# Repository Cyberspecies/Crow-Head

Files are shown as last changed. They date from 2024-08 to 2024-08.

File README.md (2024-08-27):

# Crow Head
The crow head series began as a torture test and a way to consolidate the knowledge gained. Additionally it is designed to test ideas and features that are included within other projects. The head's are allowed to be worked upon however they are not allowed to have more versions, rather once a design is finished, the majority of the design must remain and any other ideas must be tested upon the finished version or put forth to the next design.

### Note:
STL Files won't be provided due to github's file upload size restrictions. Although some files are small enough to fit, it won't be a good practice if only some files are available. There are many other programs and ways to convert step to stl so it should not be much of an issue. If it is a large issue to convert the file please make an issue with this repo or add to existing ones stating it and I will concider it, however it will be difficult to keep it up on 1 platform such at github.

## D1
The first design for this is a very simple head designed to test whether or not I could build the head within a week from start to finish. Although This version did not have the best shape, it was good enough to serve its purpose.
CrowHeadV1

## D2
The second design fixes the problems of the first design to be very comfortable to wear. This version looked more like a motor bike helmet and could be worn for hours, however I did have some issues with vision due to the mesh but ventillation was significantly improved due to it.
CrowHeadV2

## D3
This design builds off the previous variant to be a good combination between great vision and decent ventillation. Although this version looks ok, it doesnt really fix the issues rather it just reduces them a bit. This version is the first design to combine reflective plates in the eyes to allow an LED system to be integrated directly.
CrowHeadV3

## D4 (In Progress)
This design will be more of a cosplay style rather then purely hard plastic shells. The main point of this version is to be simiar to D3 however fixing many of the ventillation and vision warping issues whilst also having the capability of being water proof.

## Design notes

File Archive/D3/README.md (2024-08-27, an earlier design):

# Crow Head V3
V3 was the first to contain electrical components that were integrated directly into the build rather then being added in post. This was also the first version to have a vacuum formed visor rather then the mesh.

## Known Issues
* Visor fogs up as there is no active ventillation that is properly implemented nor any way to redirect the moist breath.
* The head retention mechanism is still lacking as the strap must be manually tensioned to the head.
* No way to attach the visor to the rest of the head without welding it or with other adhesives.

## Structure
Similar to previous models, you are required to weld the sections together, the eyes do require a bit of assembly and visor vacuum formed.
CrowHeadV3Diagram

* [Crow Head V3.f3z](Crow%20Head%20V3.f3z): Contains the entire project, however the visor buck was lost so I uploaded the latest version that was produced.
* [Crow Head V3.step](Crow%20Head%20V3.step): A step file export of the project, incase you don't have Fusion 360.
* [Crow Head V3 Cuts.step](Crow%20Head%20V3%20Cuts.step): This file contains all of the cuts required to fabricate the build.
* [Crow Head V3 Visor Buck.f3d](Crow%20Head%20V3%20Visor%20Buck.f3d): The latest version of the visor buck that was fabricated, the reason they are seperate is cause the original file deleted it somewhere during production but I didnt notice so I exported a save file.
* [Crow Head V3 Visor Buck.step](Crow%20Head%20V3%20Visor%20Buck.step): A step file version incase you don't have fusion 360.

### Note
You still have to weld the pieces together as there wasn't a way to align or connect the pieces together without using heat or adhesives. The visor must be vacuum formed as there is no mesh version for this iteration of the project as it was a full switch to vacuum forming.

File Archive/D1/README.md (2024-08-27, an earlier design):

# Crow Head V1
This is the first one of the crow head line up. Although this version is not recommended to be fabricated without foam inserts or some modifications as there are a few problems with it.

## Known Issues
* The inset eyes press against the temples causing pain after a while of wearing it.
* There is no tensioning mechanism for the head which prevents it from being worn without it rolling forward due to the unbalanced mass.
* Ball bearings of 22OD, 8ID and 7mm thickness are required to use this as the jaw joint mechanisms were not properly designed or tested yet.

## Structure
The head was not designed to be assembled uniformally, rather it must be welded together (except the eyes which are bolted with m3 screws).
CrowHeadV1Diagram

* [Crow Head V1 Cuts.step](Crow%20Head%20V1%20Cuts.step): Is the file with all the cuts required to seperate the model into printable sections
* [Crow Head V1.f3d](Crow%20Head%20V1.f3d): Is the main file in which you use to look at the model, note that there is a folder inside the bodies folder called "Cuts" which contains all of the bodies from the cut sections.
* [Crow Head V1.step](Crow%20Head%20V1.step): Simply is the step file version of the f3d file incase you don't have fusion 360.
* [Crow Head V1 Eye Cover.step](Crow%20Head%20V1%20Eye%20Cover.step): This file is designed to be printed as flat surface on the builtplate with no top and bottomlayers, we are using the 3D printer slicer software to do the meshing insead of modelling it in. Recommended settings are: 6 walls, 20% - 30% grid infill, 0.2mm layer height.

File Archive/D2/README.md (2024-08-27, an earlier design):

# Crow Head V2
This iteration of the crow head was designed around comfort rather then aesthetic accuracy, hence resulting in only a few issues.

## Known Issues
* Vision is partially impared due to the mesh, however it is greatly improved compared to V1 as the mesh covers a large area.
* There is still not a way to properly apply pressure to the head however it is not required to wear it and is only a requirement if you want to use the moving jaw feature. It is recommended that you use a small foam sheet at the back of the head to keep it in place.
* The jaw joint requires a teflon pin and is relatively weak.
* Rubber band holder has some sharp edges which can scratch the face.

## Structure
The structure is simplier then the previous version as it has a smaller frame and requires less print sessions.
CrowHeadV2Diagram

* [Crow Head V2.f3d](Crow%20Head%20V2.f3d): Main project file which contains all the necessary components required to fabricate the build.
* [Crow Head V2.step](Crow%20Head%20V2.step): A step export of the main project file.
* [Crow Head V2 Cuts.step](Crow%20Head%20V2%20Cuts.step): A step export of all the cuts.
* [Crow Head V2 Visor Pattern.step](Crow%20Head%20V2%20Visor%20Pattern.step): Similar settings as the previous version with a few adjustments. This file is designed to be printed as flat surface on the builtplate with no top and bottomlayers, we are using the 3D printer slicer software to do the meshing insead of modelling it in. Recommended settings are: 8-12 walls, 20% - 30% grid infill, 0.2mm layer height.

### Note
You need to weld the parts or spot weld them together, when welding the visor, you have to be careful but gently weld the edges to each other. Try shaping it to the visor position first before welding it.

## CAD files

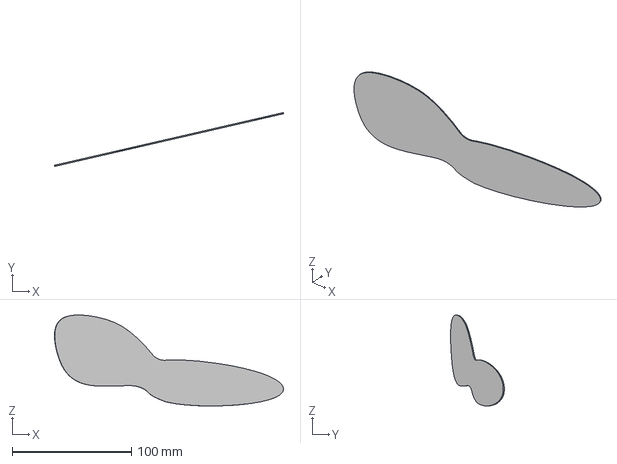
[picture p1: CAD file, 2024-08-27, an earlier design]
Archive/D1/Crow Head V1 Eye Cover.step
192.4 x 45.2 x 76.4 mm

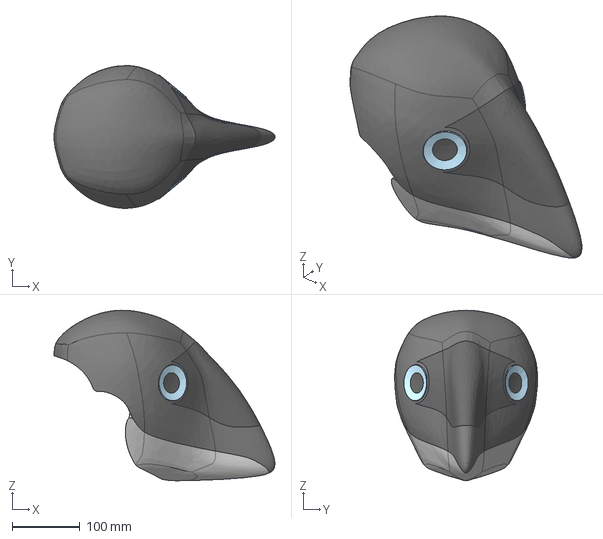
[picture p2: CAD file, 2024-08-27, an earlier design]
Archive/D2/Crow Head V2.step
325.9 x 210.4 x 251.5 mm
Eye_v15 R
Eye_v15 L

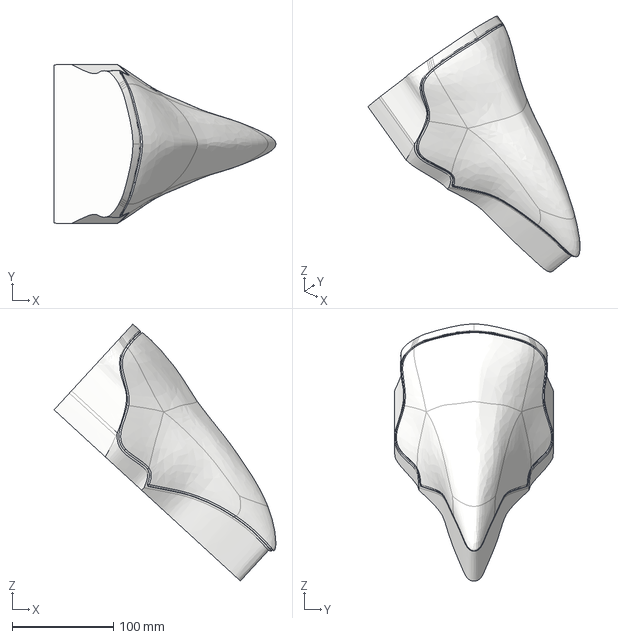
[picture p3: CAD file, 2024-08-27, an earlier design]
Archive/D3/Crow Head V3 Visor Buck.step
218.9 x 157.3 x 253.5 mm

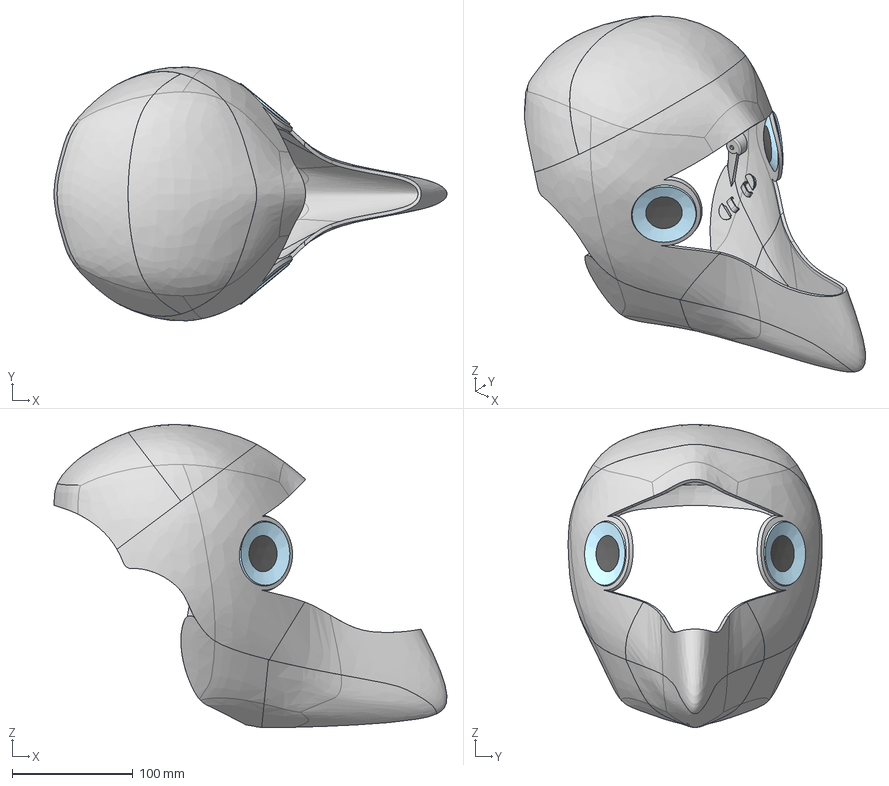
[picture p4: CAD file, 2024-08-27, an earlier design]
Archive/D2/Crow Head V2 Cuts.step
325.9 x 210.4 x 251.5 mm
Eye_v15 R
Eye_v15 L

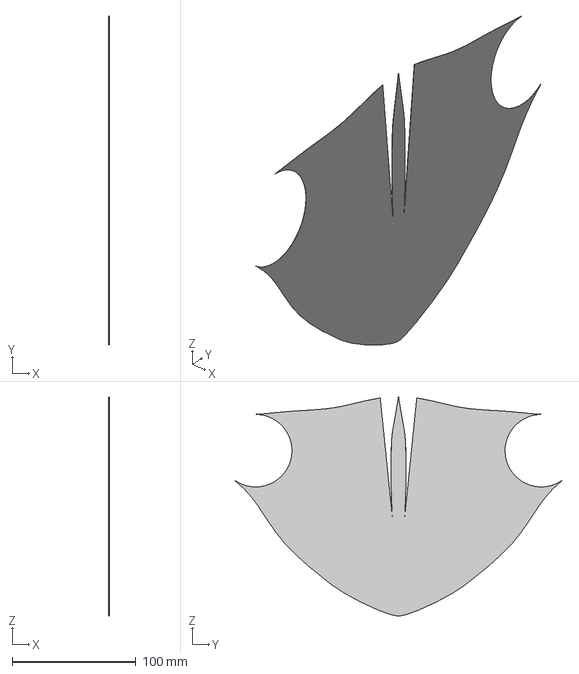
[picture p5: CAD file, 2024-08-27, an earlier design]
Archive/D2/Crow Head V2 Visor Pattern.step
0.2 x 265.4 x 177.0 mm

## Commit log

2024-08-27 Crow Head V1 Section Completed
    [Crow Head V1 Eye Cover.step]
2024-08-27 Crow Head V2 Section Completed
    [Crow Head V2 Cuts.step, Crow Head V2 Visor Pattern.step, Crow Head V2.step]
2024-08-27 Crow Head V3 Section Completed
    [Crow Head V3 Visor Buck.step]
2025-01-12 Added Some CAD Examples
2025-04-11 Added Top Level Schematic Diagram
2026-05-24 Added Rope mounting locations (incase linkage fails)
